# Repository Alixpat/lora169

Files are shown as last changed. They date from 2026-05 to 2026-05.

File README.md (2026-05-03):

# lora169

Carte LoRa 169 MHz autonome. Conformité ARCEP 2007-0689 (bande 169,4–169,475 MHz, 27 dBm p.a.r. max).

## Hardware

- **MCU** : Seeed XIAO ESP32-S3 (USB-C natif)
- **Radio** : Ebyte E22-170M30S (SX1262, IPEX), enfichable sur breakout démontable
- **Antenne** : Ebyte TX170-JKD-20 (3 dBi, fouet 200 mm), via pigtail U.FL → SMA bulkhead
- **Boîtier** : impression 3D paramétrique

## État du projet

| Pièce | Source | DRC / vérif | Statut |
|---|---|---|---|
| Carte mère (80 × 55 mm) | `hardware/lora169.kicad_*` | 0 erreur | Commandée JLCPCB |
| Breakout E22 (40,6 × 46,3 mm) | `hardware/breakout-e22/*.kicad_*` | 0 erreur | Commandé JLCPCB |
| Boîtier 3D (94 × 69 × 32,6 mm) | `enclosure/boitier-lora169.scad` | — | Commandé JLC3DP |

## Structure

```
docs/datasheets/        Datasheets PDF (E22, SX1262, AN Semtech)
hardware/               Projet KiCad carte mère
hardware/libs/          Symboles + empreintes vendorisés (Seeed, Ebyte)
hardware/breakout-e22/  Projet KiCad de la carte fille E22
enclosure/              Boîtier OpenSCAD paramétrique
```

## Outils (Debian 13)

```bash
sudo apt install kicad kicad-libraries kicad-symbols kicad-footprints kicad-packages3d openscad
```

## Ouvrir le projet

`hardware/lora169.kicad_pro` (carte mère) ou `hardware/breakout-e22/breakout-e22.kicad_pro` (breakout). Les libs `Seeed_XIAO` et `Ebyte_E22` sont déjà déclarées via `${KIPRJMOD}`.

Pour le boîtier : `openscad enclosure/boitier-lora169.scad` — modifier `show_mode` (`"box"` / `"lid"` / `"assembled"` / `"exploded"`), F6, exporter en STL.

## Régénérer les Gerbers

```bash
cd hardware
kicad-cli pcb export gerbers --output fab/ \
  --layers "F.Cu,B.Cu,F.Paste,B.Paste,F.Silkscreen,B.Silkscreen,F.Mask,B.Mask,Edge.Cuts" \
  lora169.kicad_pcb
kicad-cli pcb export drill --output fab/ lora169.kicad_pcb
cd fab && python3 -m zipfile -c ../lora169-gerbers.zip *.g* *.drl
```

## Journal des commandes

| Date | Composant | Qté | Source | Sous-total | Frais (livr./douane/PayPal) | Réduction | Total |
|---|---|-----|---|---:|---:|---:|---:|
| 2026-05-01 | Seeed XIAO ESP32-S3 | 2 | AliExpress (Seeedstudio AI Hardware Store) | 15,49 € | 4,41 € | −0,87 € | 19,03 € |
| 2026-05-01 | Ebyte E22-170M30S | 2 | AliExpress (Boutique officielle EBYTE) | 13,78 € | 4,17 € | −0,77 € | 17,18 € |
| 2026-05-03 | PCB carte mère + breakout + 2 boîtiers 3D (groupé W2026050322580094) | 5+5+2+2 | JLCPCB / JLC3DP | 14,64 € | 15,08 € | −8,52 € | 21,20 € |

**Total engagé : 57,41 €**

À commander : antenne Ebyte TX170-JKD-20 (CDSENET, ~13 €), condensateurs SMD 0805 100 nF + 10 µF (Supplier of electronic components, ~2 €), pin headers + embases femelles 1×40 (~2 €). Pigtail U.FL → SMA femelle bulkhead disponible en stock.

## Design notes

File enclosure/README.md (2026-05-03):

# Boîtier impression 3D — lora169

Boîtier paramétrique modélisé en OpenSCAD pour la carte mère lora169
(80 × 55 mm), avec breakout E22 enfichable au-dessus.

## Caractéristiques

- Dimensions intérieures : 84 × 59 × 30,6 mm (PCB + breakout + marges)
- Dimensions extérieures : 88 × 63 × 32,6 mm (avec parois 2 mm)
- Couvercle séparé de 2,5 mm vissé par 4 vis M3 traversant les piliers
- Découpe USB-C rectangulaire 11 × 5 mm sur le bord gauche, à la
  hauteur du XIAO ESP32-S3
- Trou rond Ø 6,5 mm pour SMA bulkhead sur le bord droit, en face de
  l'USB-C, à 7 mm au-dessus du plan du PCB
- 4 piliers cylindriques Ø 6 mm avec perçage Ø 2,7 mm pour vis M3
  auto-taraudantes — alignés avec les trous M3 du PCB

## Usage

Ouvrir `boitier-lora169.scad` dans **OpenSCAD**.

Variables principales en haut du fichier (à ajuster selon tes besoins) :
- `pcb_width`, `pcb_height` : dimensions du PCB
- `breakout_clearance` : hauteur libre au-dessus du PCB pour le breakout
- `wall_thickness`, `floor_thickness`, `lid_thickness` : épaisseurs
- `usb_pos_y`, `sma_pos_y`, `sma_pos_z` : positions des découpes
- `show_mode` : `"box"` (boîtier seul), `"lid"` (couvercle seul),
  `"assembled"` (les deux empilés), `"exploded"` (les deux séparés
  pour visualiser)

## Modes de visualisation

- **F5** dans OpenSCAD : preview rapide
- **F6** : rendu complet (CGAL, plus lent)
- **Fichier → Exporter en STL** : produit le fichier `.stl` à imprimer

Pour imprimer le boîtier ET le couvercle séparément (deux STL distincts) :
1. Régler `show_mode = "box"`, F6, exporter en `boitier-lora169-box.stl`
2. Régler `show_mode = "lid"`, F6, exporter en `boitier-lora169-lid.stl`

## Paramètres d'impression recommandés

- Matériau : PLA ou PETG
- Hauteur de couche : 0,2 mm
- Remplissage : 20-30 % (pas critique mécaniquement)
- Supports : nécessaires pour le creux intérieur du boîtier (sinon le
  fond ne peut pas s'imprimer correctement). Couvercle imprimable sans
  support (pièce plate).
- Périmètres : 3-4 (pour la solidité des parois)

## Visserie

- 4 × vis M3 auto-taraudantes longueur 8-10 mm (pour fixer le PCB sur
  les piliers depuis le dessus à travers les trous du PCB), ou
- 4 × vis M3 longueur 16-20 mm pour traverser le couvercle ET le PCB
  jusqu'aux piliers (option « tout-en-un »)

À ce jour, le code prévoit l'option « tout-en-un » : la vis traverse
le couvercle (Ø 3,4), passe à travers le trou du PCB (Ø 3,2), et se
visse dans le pilier (Ø 2,7 — taraudage fait par la vis elle-même).

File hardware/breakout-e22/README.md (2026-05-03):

# Breakout E22 (carte fille)

Carte adaptatrice qui transforme le module Ebyte E22-170M30S (SMD, pads
en bord) en module DIP enfichable via deux pin headers 1×11 broches au
pas 2,54 mm. Permet de changer de fréquence (170 / 400 / 900 MHz) sur
la carte mère sans dessouder.

## Conception

Design propre fait pour ce projet, avec :

- 1× module E22-xxxM30S (mécanique commune à 170/400/900 MHz)
- 2× condensateurs de découplage 100 nF + 10 µF (céramique X7R 0805)
  au plus près des pins VCC, pour absorber le pic TX 30 dBm (~620 mA)
- 2× pin headers 1×11 broches au pas 2,54 mm sur les bords longs
- VCC alimenté en 5 V depuis VBUS du XIAO côté carte mère, pour
  permettre la pleine puissance 30 dBm hardware
- Plan de masse continu sur la face arrière

## Caractéristiques techniques

- Format PCB : **40,6 × 46,3 mm** (compact, à peine plus large que
  le module E22 lui-même de 24 × 38,5 mm)
- Espacement entre les deux pin headers J1/J2 : **32,1 mm** centre à
  centre — à respecter sur la carte mère (embases femelles 1×11)
- Pistes signal en 0,2 mm, piste alim +5V en 0,4 mm pour absorber le
  pic 620 mA en TX 30 dBm
- Pads GND en pleine connexion à la zone GND (sans thermal relief)
  pour minimiser l'inductance de retour

## Valeurs de découplage — sources

Le combo **100 nF + 10 µF céramique 0805** est validé par la pratique
de plusieurs designs publics éprouvés à 30 dBm voire 33 dBm :

- [eigenlucy/e22900m30s](https://github.com/eigenlucy/e22900m30s) :
  E22-900M30S, alim 5 V, 10 µF (0805) + 100 nF (0402)
- [KaliAssistant/MeshAdv_piHAT_v2](https://github.com/KaliAssistant/MeshAdv_piHAT_v2) :
  E22-900M33S (33 dBm = 2 W !), 10 µF + 100 nF répartis sur les rails
- [andrew-moroz/xiao-ble-pcb](https://github.com/andrew-moroz/xiao-ble-pcb) :
  E22-900M30S, MiniBoost 5 V + 100 µF buffering en sortie

Ni la datasheet E22 ni les notes Semtech (AN1200.37, AN1200.40) ne
donnent de valeurs explicites pour le découplage externe d'un module
E22 fini — la datasheet recommande juste un « external ceramic filter
capacitor ». Les 100 nF + 10 µF sont donc retenus comme convention
d'industrie validée empiriquement.

## Mapping J1 / J2 (côté carte mère)

| Pin header | Broche | Signal | Pad E22 |
|---|---|---|---|
| J2 | 1-5, 11| GND | 1-5, 11 |
| J2 | 6 | RXEN | 6 |
| J2 | 7 | TXEN | 7 |
| J2 | 8 | NC (DIO2)| 8 |
| J2 | 9-10 | +5V (VCC)| 9-10 |
| J1 | 1, 9, 11| GND | 12, 20, 22 |
| J1 | 2 | DIO1 | 13 |
| J1 | 3 | BUSY | 14 |
| J1 | 4 | NRST | 15 |
| J1 | 5 | MISO | 16 |
| J1 | 6 | MOSI | 17 |
| J1 | 7 | SCK | 18 |
| J1 | 8 | NSS | 19 |
| J1 | 10 | NC (ANT) | 21 (sortie RF, non utilisée en IPEX) |

## Statut

- DRC : 0 erreur, 0 unconnected
- Gerbers générés : `breakout-e22-gerbers.zip`
- Prêt à fabriquer chez JLCPCB / PCBWay

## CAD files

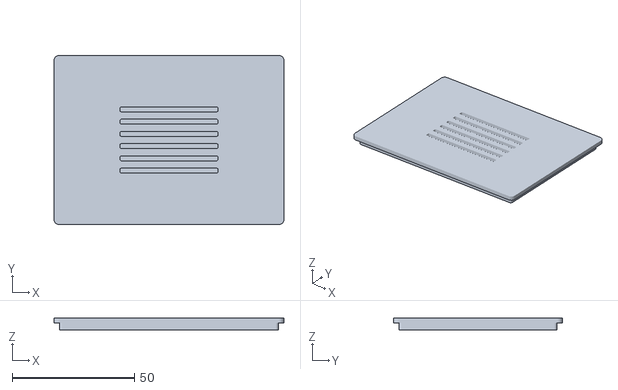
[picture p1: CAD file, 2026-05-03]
enclosure/boitier-lora169-lid.stl
94.0 x 69.0 x 5.00

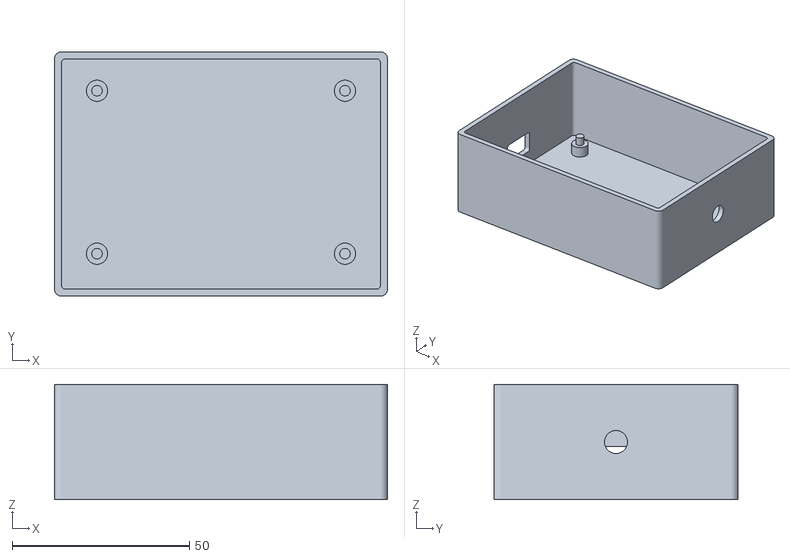
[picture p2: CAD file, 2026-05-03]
enclosure/boitier-lora169-box.stl
94.0 x 69.0 x 32.6

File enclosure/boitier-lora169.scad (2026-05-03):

// =============================================================
//  Boîtier paramétrique pour la carte mère lora169
//
//  PCB 80 × 55 mm (mesuré depuis hardware/lora169.kicad_pcb).
//  4 trous M3 aux coins : (5,5) (75,5) (5,51) (75,51) en repère PCB.
//  USB-C XIAO en bord gauche, à Y=27,5 du PCB.
//  SMA bulkhead centré sur la face droite du boîtier.
//
//  Système de fermeture : couvercle plat avec un rebord intérieur
//  qui s'engage par friction dans le creux du boîtier (comme un
//  couvercle de bocal). Pas de vis, pas de clip.
// =============================================================

// ---------- Paramètres ajustables ----------

// Dimensions PCB carte mère (mesurées dans KiCad)
pcb_width  = 80;
pcb_height = 55;
pcb_thickness = 1.6;

// Trous M3 du PCB (positions relatives au coin bas-gauche du PCB)
hole_offset_x        = 5;   // X depuis le bord gauche/droit
hole_offset_y_top    = 5;   // Y depuis le bord HAUT
hole_offset_y_bottom = 4;   // Y depuis le bord BAS (asymétrie : J2 broche 11 trop proche)

// Hauteur libre nécessaire au-dessus du PCB pour breakout E22 + module enfiché
// 25 mm = ~14 mm pour le breakout + ~11 mm de marge pour le saisir à la main
// et l'extraire facilement du boîtier
breakout_clearance = 25;

// Position de l'USB-C (centre, depuis le coin bas-gauche du PCB)
usb_pos_y = 27.5;     // alignement Y avec le centre du XIAO
usb_cutout_w = 13;    // largeur découpe — accommode le boîtier plastique du câble
usb_cutout_h = 8;     // hauteur découpe — accommode les câbles renforcés

// SMA bulkhead — centré sur la face droite
sma_diameter = 6.5;

// Épaisseurs
wall_thickness  = 2;
floor_thickness = 2;
lid_thickness   = 2;
inner_margin    = 5;  // jeu autour du PCB sur les 4 côtés

// Piliers de centrage du PCB (2 étages, sans vis)
pillar_d_lower = 6;   // Ø étage bas (épaulement du PCB)
pillar_h_lower = 4;   // hauteur étage bas
pillar_d_upper = 3;   // Ø étage haut (passe dans le trou Ø 3,2 du PCB)
pillar_h_above_pcb = 1.5;  // dépassement de la partie fine au-dessus du PCB

// Couvercle (rebord intérieur d'engagement par friction)
lid_lip_height    = 3;     // hauteur du rebord descendant dans le boîtier
lid_lip_clearance = 0.3;   // jeu du rebord avec les parois (impression 3D)

// Ventilation du couvercle (fentes parallèles centrées)
vent_count   = 6;          // nombre de fentes
vent_length  = 40;         // longueur d'une fente (mm)
vent_width   = 2;          // largeur d'une fente (mm)
vent_spacing = 3;          // espacement entre fentes (mm)

// Mode d'affichage : "box" | "lid" | "assembled" | "exploded"
show_mode = "exploded";

// ---------- Calculs internes ----------

inner_width  = pcb_width + 2 * inner_margin;
inner_height = pcb_height + 2 * inner_margin;
inner_depth  = pillar_h_lower + pcb_thickness + breakout_clearance;

outer_width  = inner_width + 2 * wall_thickness;
outer_height = inner_height + 2 * wall_thickness;
outer_depth  = inner_depth + floor_thickness;

pcb_x = wall_thickness + inner_margin;
pcb_y = wall_thickness + inner_margin;
pcb_z = floor_thickness + pillar_h_lower;

// ---------- Modules ----------

// Boîte rectangulaire à coins verticaux arrondis (rayon r en XY)
module rounded_box(w, h, d, r) {
    hull() {
        for (x = [r, w - r])
            for (y = [r, h - r])
                translate([x, y, 0])
                    cylinder(r = r, h = d, $fn = 48);
    }
}

module pillar() {
    h_top = pillar_h_lower + pcb_thickness + pillar_h_above_pcb;
    union() {
        cylinder(h = pillar_h_lower, d = pillar_d_lower, $fn = 48);
        cylinder(h = h_top, d = pillar_d_upper, $fn = 32);
    }
}

module pillars() {
    for (px = [hole_offset_x, pcb_width - hole_offset_x])
        for (py = [hole_offset_y_top, pcb_height - hole_offset_y_bottom])
            translate([pcb_x + px, pcb_y + py, floor_thickness])
                pillar();
}

// Découpe USB-C dans la paroi gauche (X = 0), avec coins arrondis r=1 mm
module usb_cutout() {
    r = 1;  // rayon des coins arrondis
    translate([
        -1,
        pcb_y + usb_pos_y - usb_cutout_w / 2,
        pcb_z + pcb_thickness - 0.5
    ])
        hull() {
            for (cy = [r, usb_cutout_w - r])
                for (cz = [r, usb_cutout_h - r])
                    translate([0, cy, cz])
                        rotate([0, 90, 0])
                            cylinder(h = wall_thickness + 2, r = r, $fn = 32);
        }
}

// Trou SMA dans la paroi droite — centré
module sma_hole() {
    translate([outer_width + 1, outer_height / 2, outer_depth / 2])
        rotate([0, -90, 0])
            cylinder(h = wall_thickness + 2, d = sma_diameter, $fn = 48);
}

// Boîtier (cuvette ouverte sur le dessus, arêtes verticales arrondies)
module box() {
    difference() {
        rounded_box(outer_width, outer_height, outer_depth, 2);

        // Creux intérieur (arêtes verticales légèrement arrondies aussi)
        translate([wall_thickness, wall_thickness, floor_thickness])
            rounded_box(inner_width, inner_height, inner_depth + 1, 1);

        usb_cutout();
        sma_hole();
    }
    pillars();
}

// Fentes de ventilation centrées sur le couvercle
module vents() {
    block_h = vent_count * vent_width + (vent_count - 1) * vent_spacing;
    y_start = (outer_height - block_h) / 2;
    x_start = (outer_width - vent_length) / 2;

    for (i = [0 : vent_count - 1])
        translate([
            x_start,
            y_start + i * (vent_width + vent_spacing),
            -1
        ])
            rounded_box(vent_length, vent_width, lid_thickness + 2, 0.5);
}

// Couvercle plat avec rebord intérieur d'engagement par friction
// Arêtes verticales arrondies + fentes de ventilation centrées
module lid() {
    difference() {
        union() {
            // Plaque supérieure : couvre toute la surface du boîtier
            rounded_box(outer_width, outer_height, lid_thickness, 2);

            // Rebord intérieur qui descend dans le creux par friction
            translate([
                wall_thickness + lid_lip_clearance,
                wall_thickness + lid_lip_clearance,
                -lid_lip_height
            ])
                rounded_box(
                    inner_width - 2 * lid_lip_clearance,
                    inner_height - 2 * lid_lip_clearance,
                    lid_lip_height,
                    1
                );
        }

        // Soustraction des fentes de ventilation
        vents();
    }
}

// ---------- Affichage ----------
if (show_mode == "box") {
    box();
}
else if (show_mode == "lid") {
    lid();
}
else if (show_mode == "assembled") {
    box();
    translate([0, 0, outer_depth])
        lid();
}
else if (show_mode == "exploded") {
    box();
    translate([0, 0, outer_depth + 25])
        lid();
}

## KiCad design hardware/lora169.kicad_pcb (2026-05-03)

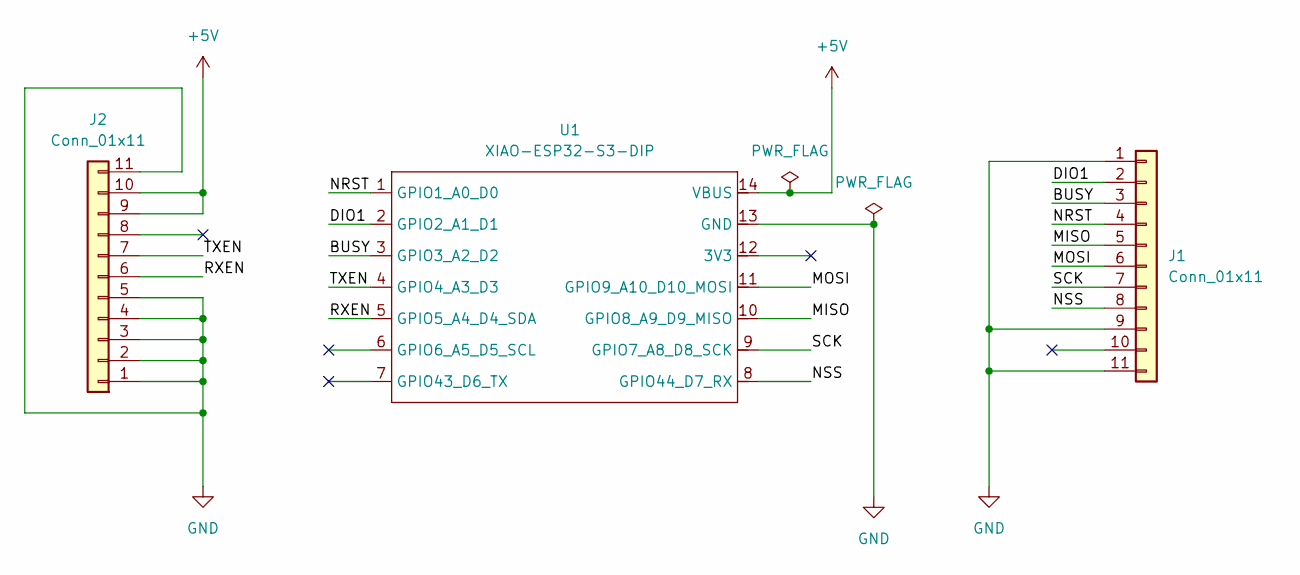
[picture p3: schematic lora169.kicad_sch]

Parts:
J1, J2: Conn_01x11; PinSocket_1x11_P2.54mm_Vertical
U1: XIAO-ESP32-S3-DIP

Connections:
+5V: J2.9, J2.10, U1.14 (VBUS)
/BUSY: J1.3, U1.3 (GPIO3_A2_D2)
/DIO1: J1.2, U1.2 (GPIO2_A1_D1)
/MISO: J1.5, U1.10 (GPIO8_A9_D9_MISO)
/MOSI: J1.6, U1.11 (GPIO9_A10_D10_MOSI)
/NRST: J1.4, U1.1 (GPIO1_A0_D0)
/NSS: J1.8, U1.8 (GPIO44_D7_RX)
/RXEN: J2.6, U1.5 (GPIO5_A4_D4_SDA)
/SCK: J1.7, U1.9 (GPIO7_A8_D8_SCK)
/TXEN: J2.7, U1.4 (GPIO4_A3_D3)
GND: J1.1, J1.9, J1.11, J2.1, J2.2, J2.3, J2.4, J2.5, J2.11, U1.13 (GND)

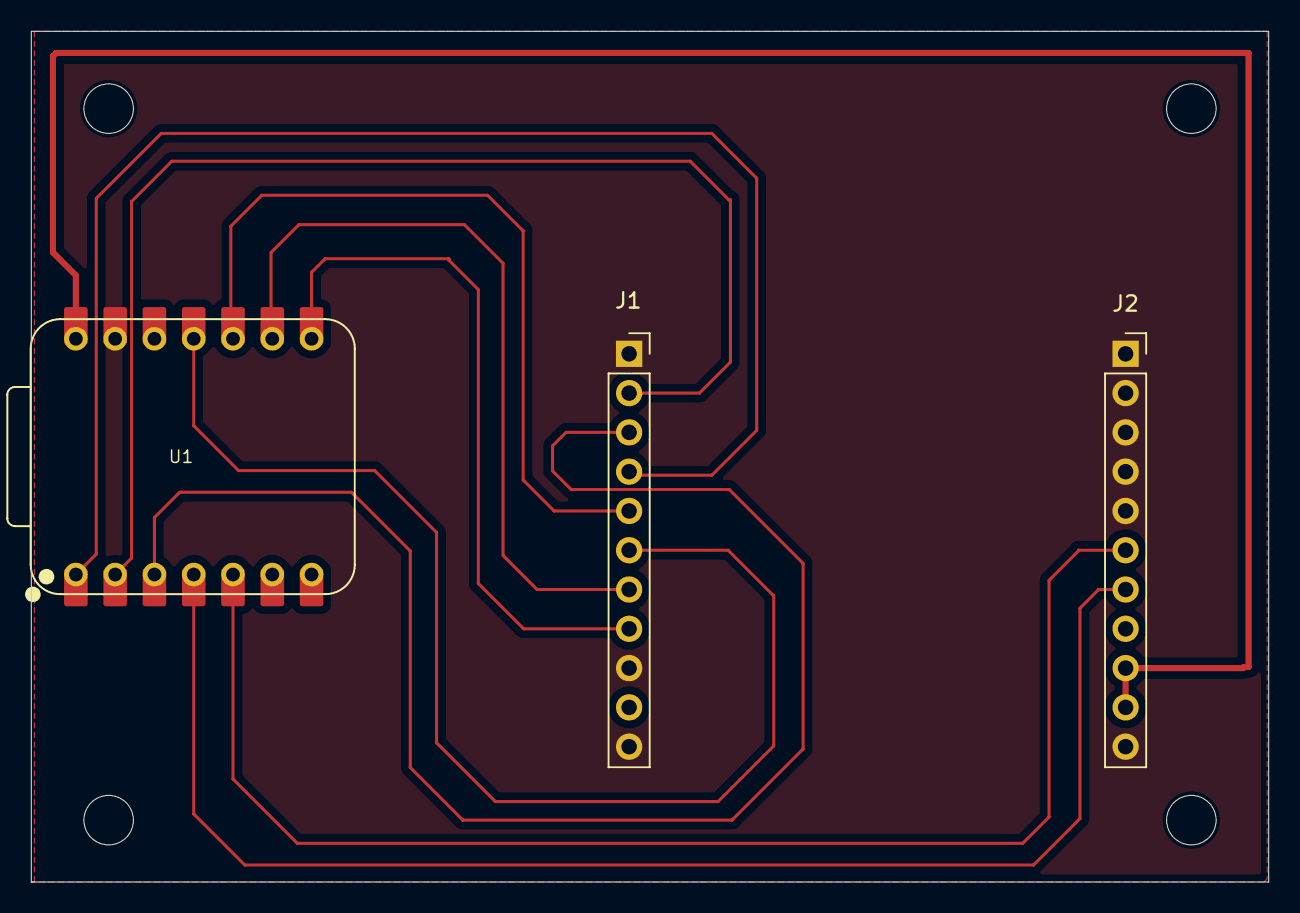
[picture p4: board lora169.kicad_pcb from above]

Board: 2 copper layers, 80.0 x 55.0 mm, 3 parts (0 on the bottom side), 11 nets.

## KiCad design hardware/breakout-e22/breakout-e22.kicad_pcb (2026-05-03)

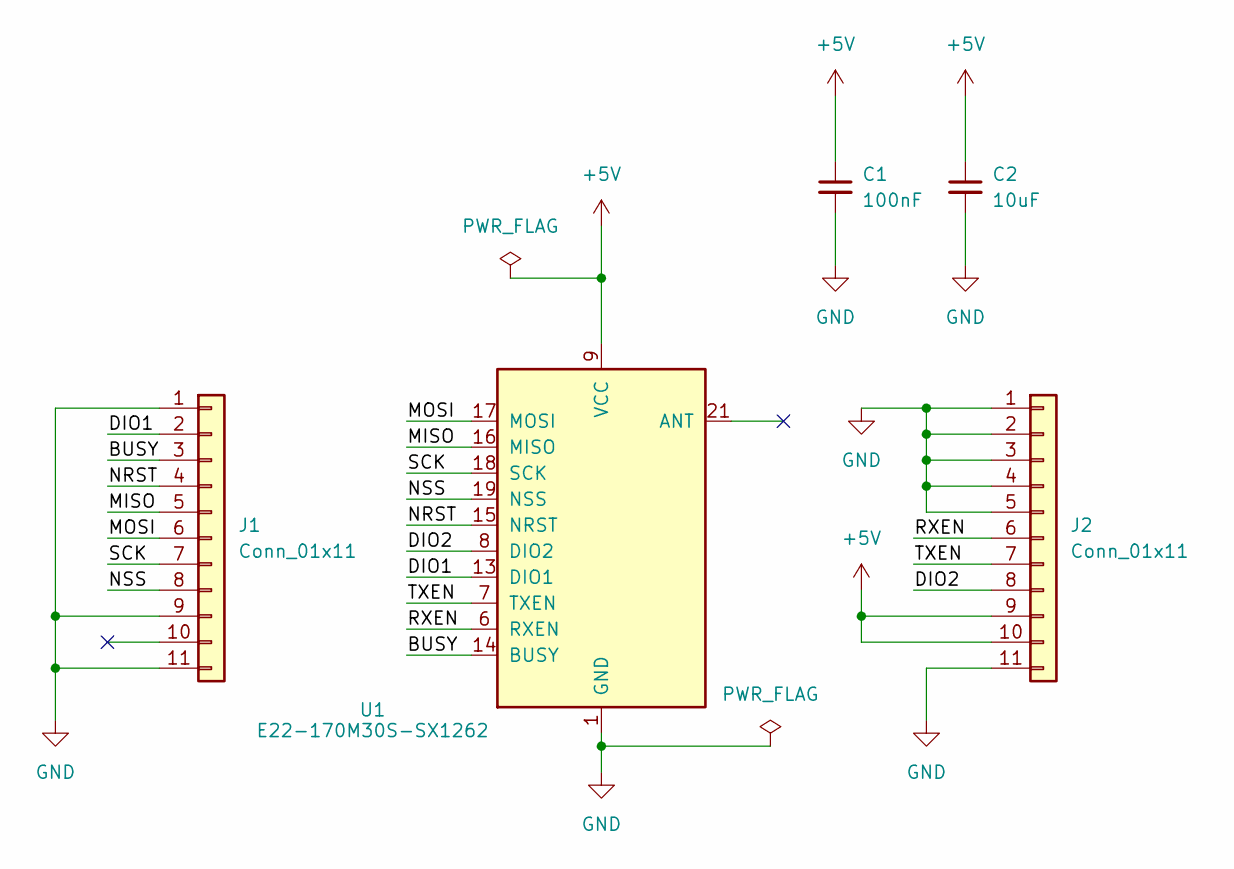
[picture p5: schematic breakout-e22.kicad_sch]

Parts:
C1: 100nF; C_0805_2012Metric
C2: 10uF; C_0805_2012Metric
J1, J2: Conn_01x11; PinHeader_1x11_P2.54mm_Vertical
U1: E22-170M30S-SX1262

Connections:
+5V: C1.1, C2.1, J2.9, J2.10, U1.9 (VCC), U1.10 (VCC)
/BUSY: J1.3, U1.14 (BUSY)
/DIO1: J1.2, U1.13 (DIO1)
/DIO2: J2.8, U1.8 (DIO2)
/MISO: J1.5, U1.16 (MISO)
/MOSI: J1.6, U1.17 (MOSI)
/NRST: J1.4, U1.15 (NRST)
/NSS: J1.8, U1.19 (NSS)
/RXEN: J2.6, U1.6 (RXEN)
/SCK: J1.7, U1.18 (SCK)
/TXEN: J2.7, U1.7 (TXEN)
GND: C1.2, C2.2, J1.1, J1.9, J1.11, J2.1, J2.2, J2.3, J2.4, J2.5, J2.11, U1.1 (GND), U1.2 (GND), U1.3 (GND), U1.4 (GND), U1.5 (GND), U1.11 (GND), U1.12 (GND), U1.20 (GND), U1.22 (GND)

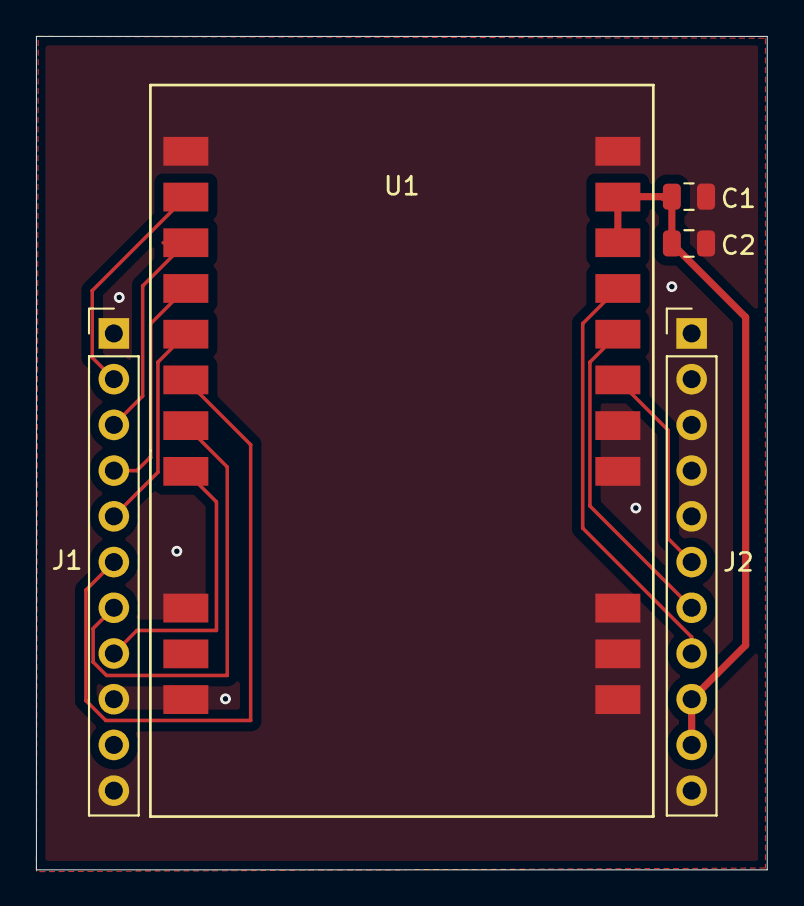
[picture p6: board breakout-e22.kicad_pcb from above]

Board: 2 copper layers, 40.6 x 46.3 mm, 5 parts (0 on the bottom side), 12 nets.

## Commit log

2026-05-01 Initialisation du projet lora169
    README de présentation, .gitignore KiCad, et squelette du projet KiCad 9
    vide dans hardware/ (schéma + PCB). Cible : carte LoRa 169 MHz autour
    d'un XIAO ESP32-S3 et d'un module Ebyte E22-170M30S.
    [lora169.kicad_pcb, lora169.kicad_sch]
2026-05-01 Ajout des datasheets et de la librairie KiCad du XIAO ESP32-S3
    - docs/datasheets/ : manuel utilisateur E22-170M30S (Ebyte V1.2,
    2026-02-06), datasheet officielle Semtech SX1261/2 V1.1 et deux
    notes d'application (best performance + reference design).
    - hardware/libs/seeed/ : symboles XIAO Series et empreintes
    XIAO-ESP32-S3 DIP + SMD vendorisés depuis OPL_Kicad_Library
    (commit 3be8215, dernier en format KiCad 9 — les commits suivants
    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
2026-05-01 Ajout de la librairie KiCad pour le module E22-170M30S
    Symbole et empreinte adaptés des MR !2826 (kicad-symbols) et !2345
    (kicad-footprints) du contributeur TheSillyMouse, non encore mergées
    dans les librairies officielles KiCad. Symbole converti depuis le
    format legacy .lib via kicad-cli sym upgrade ; renommé en
    E22-170M30S-SX1262 puisque toute la famille E22-xxxM30S partage la
    même mécanique. À valider au pied à coulisse sur un module physique
    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
2026-05-02 Avancement schéma et PCB carte mère lora169
    Schéma : pose XIAO ESP32-S3 et E22-170M30S, condensateurs de découplage
    100nF + 10µF sur le rail VCC du E22, labels de signaux pour les
    liaisons SPI/IO entre les deux modules, power ports +3V3/GND avec
    PWR_FLAG sur les rails alim. NC flags posés sur les pins volontairement
    non connectées (E22 DIO2 et ANT en version IPEX, XIAO D5/D6/VBUS).
    PCB : empreintes importées depuis le schéma, placement initial des
    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
    [lora169.kicad_pcb, lora169.kicad_sch]
2026-05-02 Ajout du breakout E22 conçu from scratch
    Carte fille adaptatrice qui transforme le module E22-xxxM30S (SMD avec
    pads en bord) en module DIP enfichable via deux pin headers 1×11
    broches au pas 2,54 mm. Permet de changer de fréquence (170/400/900 MHz)
    sur la carte mère sans dessouder, en bénéficiant d'une mécanique
    identique entre toutes les variantes E22-xxxM30S.
    Schéma : 1× E22-170M30S-SX1262 + 2× condensateurs de découplage VCC
    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
    [E22-XXXMXXS.brd, E22-XXXMXXS.sch, breakout-e22.kicad_pcb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]
2026-05-03 Refonte from scratch carte mère adaptée au breakout E22 + finitions
    Carte mère reconçue pour recevoir le breakout E22 plutôt que le module
    soudé direct. Trois composants seulement : XIAO ESP32-S3 DIP, plus
    deux embases femelles 1×11 (PinSocket_2.54mm) espacées de 32,1 mm
    centre à centre pour matcher les pin headers du breakout.
    Schéma : labels signaux (NRST, DIO1, BUSY, TXEN, RXEN, NSS, SCK, MISO,
    MOSI), power ports +5V (au lieu de +3V3) sur la pin VBUS du XIAO et
    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
    [breakout-e22.kicad_pcb, lora169.kicad_pcb, lora169.kicad_sch]
2026-05-03 Trous M3 + audit final + boîtier OpenSCAD
    Carte mère :
    - Ajout de 4 trous de fixation MountingHole_3.2mm_M3 aux coins
    (95,55) (165,55) (95,101) (165,101). Le trou bas-droit est
    asymétrique en Y (Y=101 au lieu de 100) pour éviter le
    courtyards_overlap avec J2 broche 11.
    - Audit final : contour 80×55 mm confirmé, 99 segments en F.Cu
    largeurs 0,2 mm (signal) et 0,4 mm (alim +5V), 2 zones GND
    (F.Cu + B.Cu) en pleine connexion, 0 via (les pads THT des
    PinSockets servent de via naturels), 11 nets nommés cohérents
    avec le schéma.
    - DRC : 0 erreur, 0 pad non connecté, 0 erreur d'empreinte.
    Prête à fabriquer chez JLCPCB / PCBWay.
    Boîtier 3D :
    - Modélisation OpenSCAD par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
    [E22-XXXMXXS.brd, E22-XXXMXXS.sch, boitier-lora169.scad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]
2026-05-03 README simplifié + cleanup STL + commande PCB JLCPCB enregistrée
    README condensé : table de statut, structure du dépôt, outils, procédure
    de régénération des Gerbers en CLI, journal des commandes à jour.
    .gitignore : exclusion des STL régénérables depuis le .scad. Suppression
    du STL précédemment commité par erreur (boitier-lora169.stl).
    show_mode du boîtier OpenSCAD passé à "lid" (état de travail courant).
    Commande JLCPCB W2026050322580094 ajoutée au journal : 5× carte mère +
    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
    [boitier-lora169.scad, boitier-lora169.stl]
2026-05-03 Ajout des STL release du boîtier (visualisables sur GitHub)
    Les 2 STL générés depuis boitier-lora169.scad (modes "box" et "lid")
    sont maintenant versionnés. GitHub les rend visualisables en 3D natif
    dans l'interface web — utile pour partager le design sans installer
    OpenSCAD.
    .gitignore : ne plus ignorer tous les .stl du dossier, juste l'ancien
    boitier-lora169.stl combiné qui n'est plus utilisé.
    [boitier-lora169-box.stl, boitier-lora169-lid.stl]
2026-05-03 README : retrait ligne antennes pas encore commandées, total recalculé
    Les antennes TX170-JKD-20 figuraient dans le journal alors qu'elles
    n'avaient pas été commandées. Ligne retirée du tableau des commandes
    effectives.
    Total engagé révisé à 57,41 € (XIAO + E22 + PCB/3D), avec note de ce
    qui reste à commander (antennes, condos, pin headers).
